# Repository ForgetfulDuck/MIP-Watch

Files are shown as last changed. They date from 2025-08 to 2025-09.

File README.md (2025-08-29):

# STM32 Fitness Tracker with MIP Display
A simple fitness tracker based on the STM32U0 microcontroller that utilizes low-power modes, DMA-based I2C data transfers, and an ultra-low-power MIP display to maximize battery life.
___
### Hardware Components
| Description | Part |
| :--- | ---:|
| Arm Cortex-M0+ MCU  | [STM32U0](/Datasheets/stm32u031f4.pdf) |
| Accelerometer with built-in pedometer  | [LSM6DSR](/Datasheets/LSM6DSR.pdf) |
| RTC  | [MAX31331](/Datasheets/MAX31331.pdf) |
| MIP display  | [TN0104ANVAANN](/Datasheets/TN0104ANVAANN-GN00_Spec.pdf) |
| Coin Cell  (4.2-3.6V, 120mAh )  | LIR2450 |

### Software + Tools
- PCB Design: KiCAD (Schematic and 4-layer board design)
- Firmware Development: STM32CubeIDE with HAL drivers
- Programming: ST-Link V2 debugger/programmer
- Version Control: Git with structured project management
___
### PCB Design
**4-Layer Stackup: Signal - GND - Power - Signal**:
|  | Image | Contents |
| :---:  | :---: | :---: |
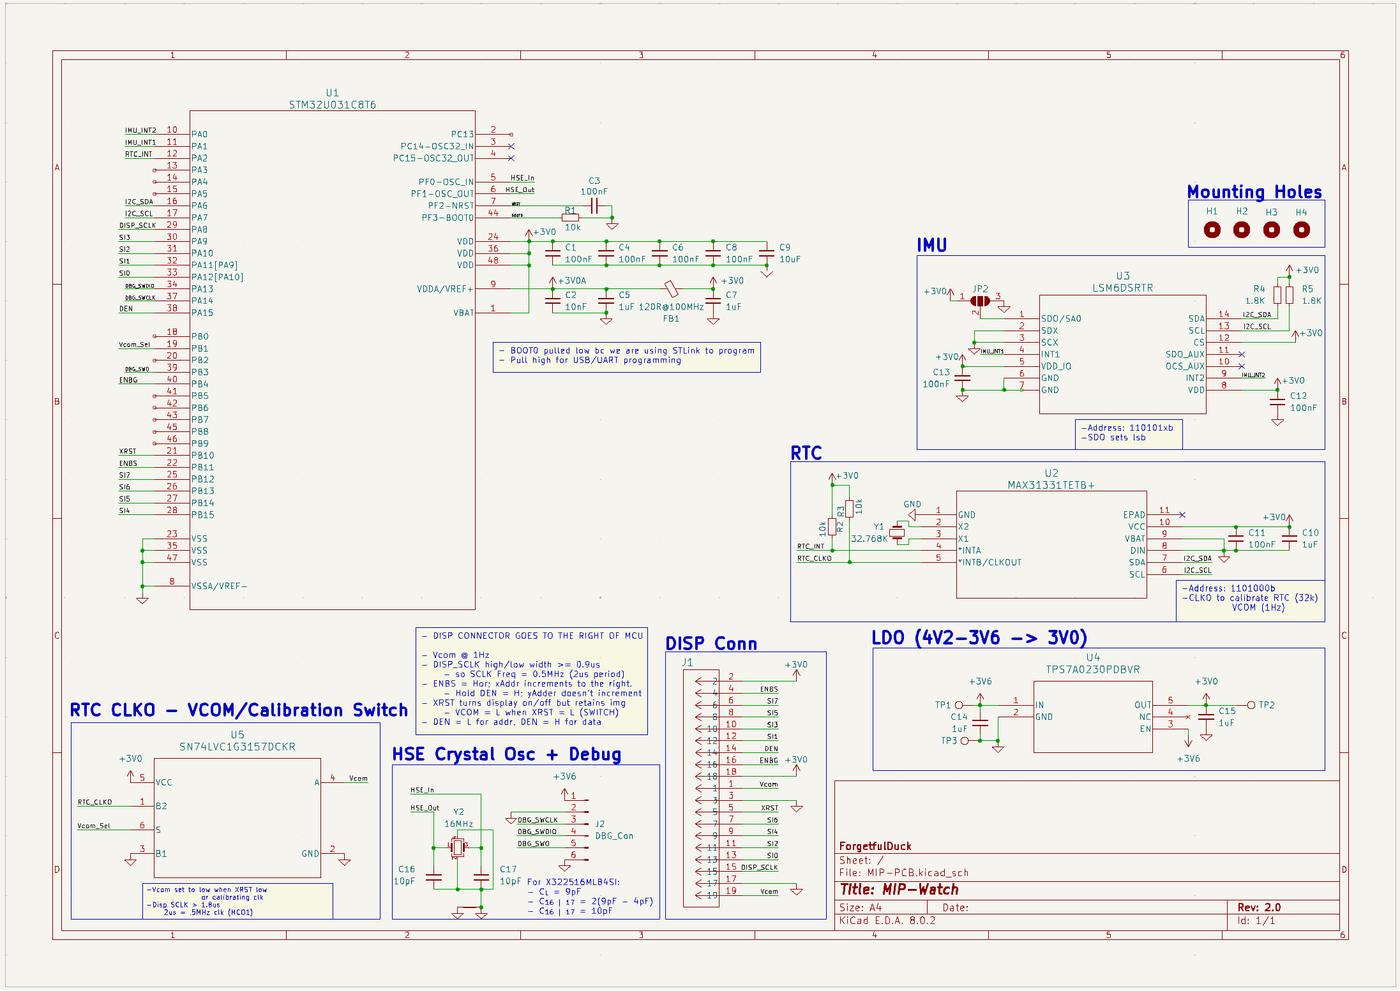
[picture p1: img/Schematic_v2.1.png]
Schematic
|Schematic| |  |
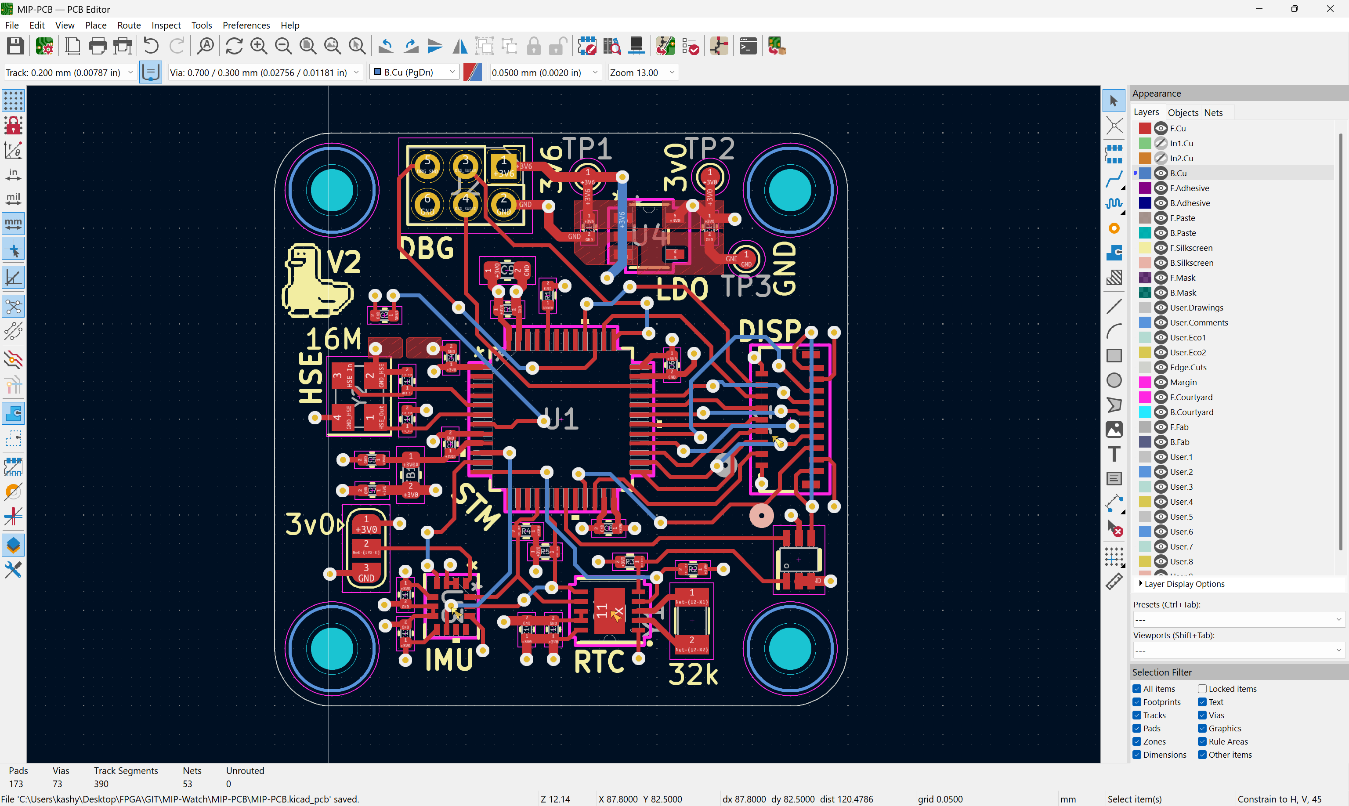
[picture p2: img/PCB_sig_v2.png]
|Signal| | Short traces, Decoupling caps, Copper pours, Test pads |
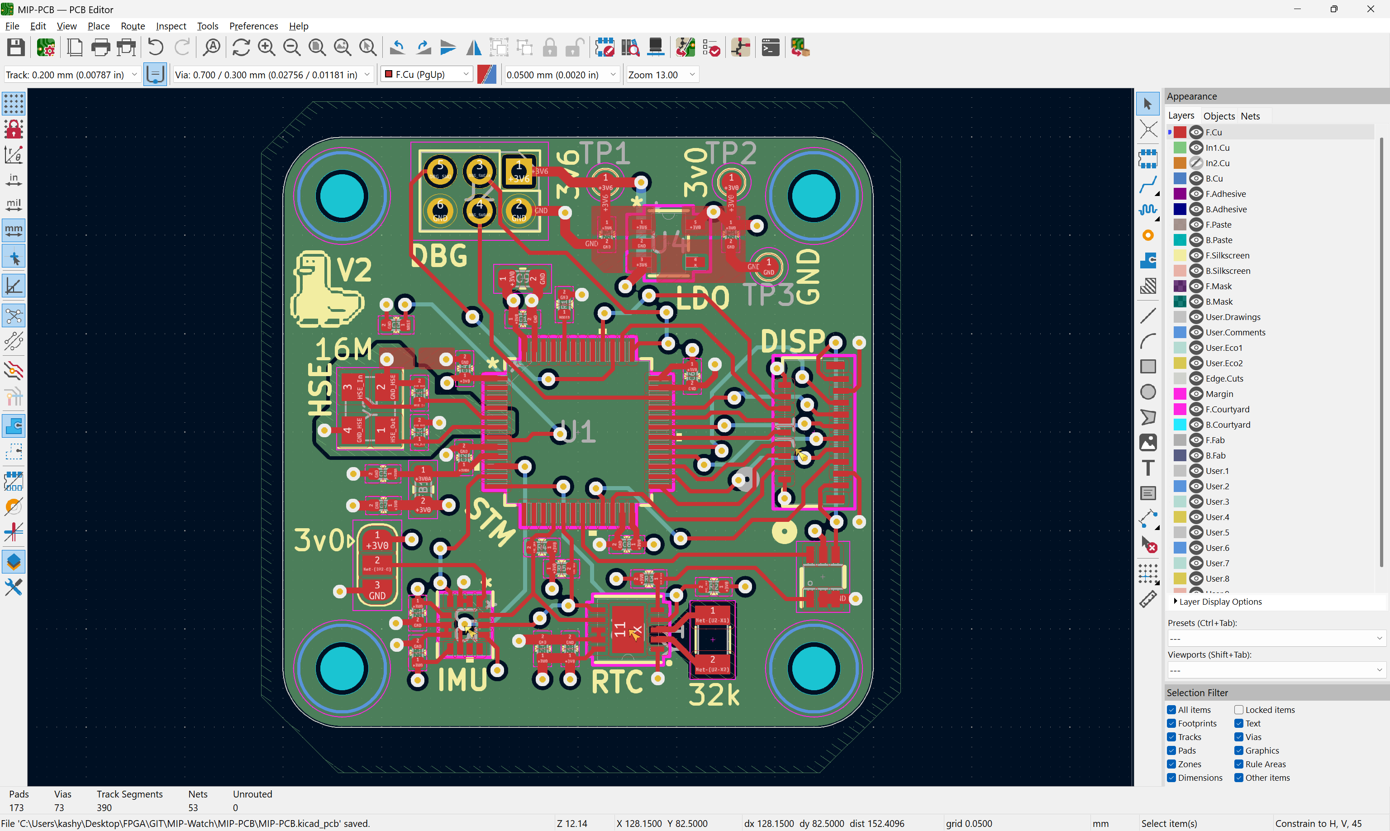
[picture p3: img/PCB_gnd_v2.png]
|GND| | A continuous ground plane to maximize signal integrity and minimize EMI |
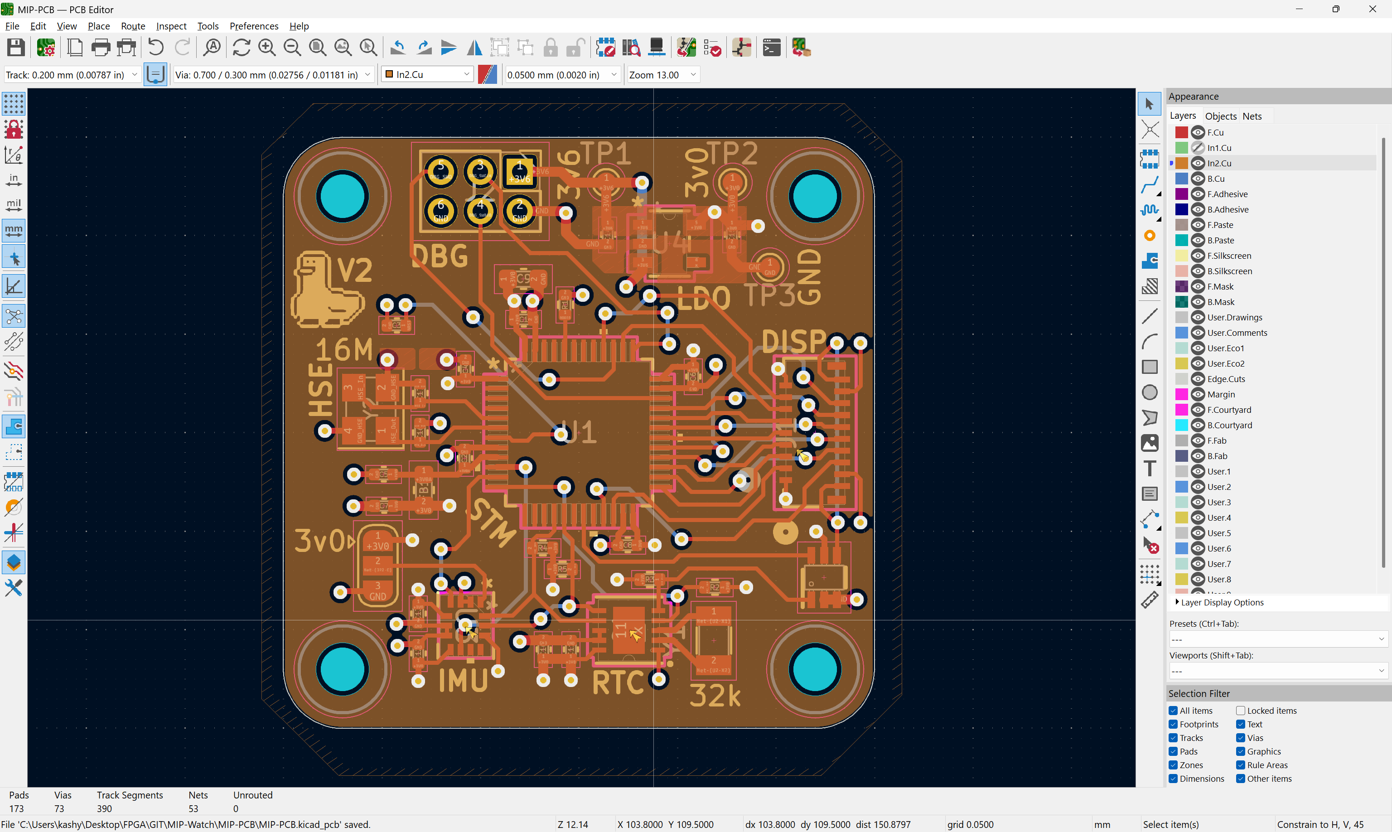
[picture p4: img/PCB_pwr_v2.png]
|Power| |  A clean power plane for efficient power distribution with minimal voltage drop |
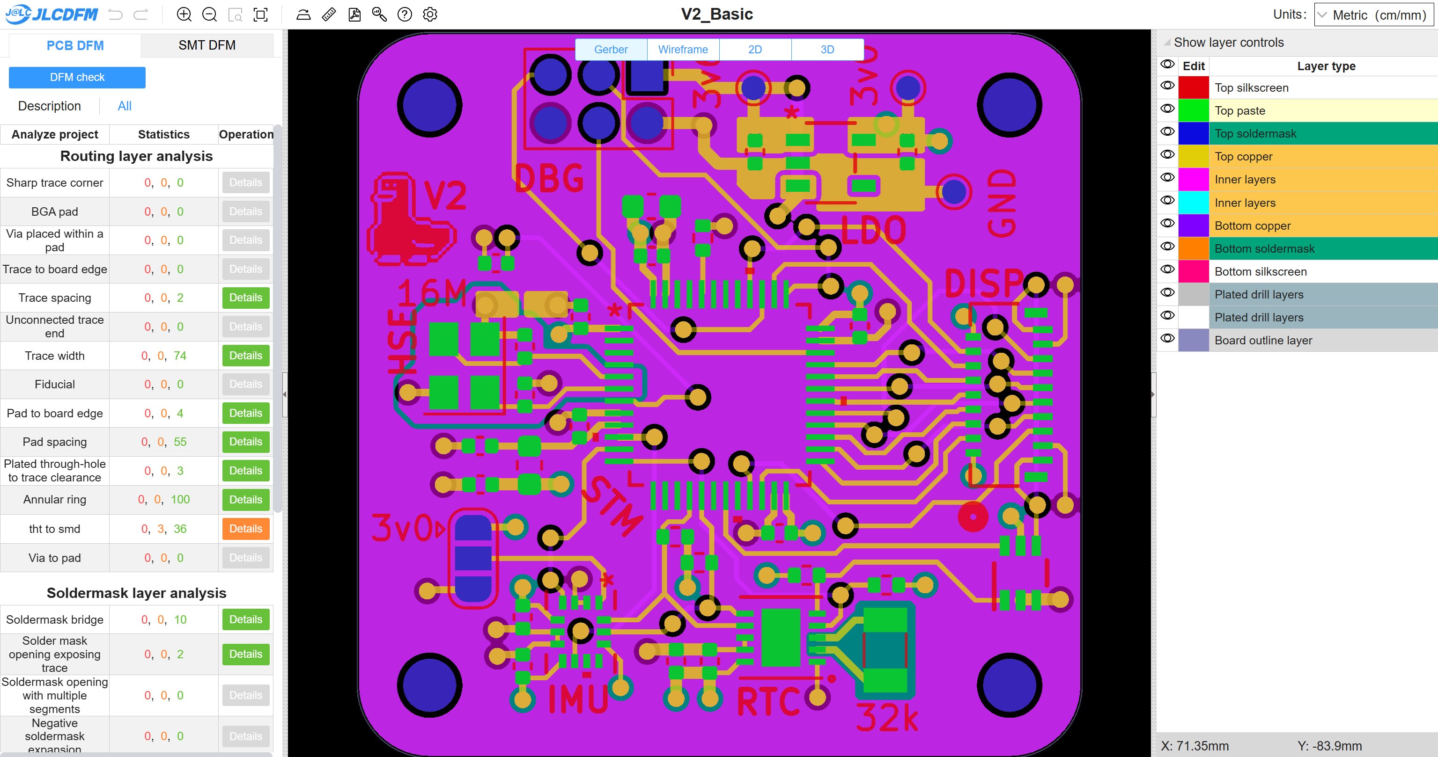
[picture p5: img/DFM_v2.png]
DFM
|DFM | | Designed around JLCPCB's design constraints, with design-for-testability (DFT) considerations, including test points and adequate component spacing. |
___

### System Architecture

```mermaid
---
config:
  theme: base
  themeVariables:
    primaryColor: "#2b3137"
    primaryTextColor: "#fafbfc"
    primaryBorderColor: "#fafbfc"
    lineColor: "#fafbfc"
    secondaryColor: "#24292e"
    tertiaryColor: "#0D1117"
    fontSize: "16px"
    fontFamily: "Segoe UI, Helvetica, Arial, sans-serif"
  nodeSpacing: 30
  rankSpacing: 30
---
flowchart TD
   subgraph SystemArchitecture [ ]
      A[Power On Reset] --> B[MCU Core Initialization<br>HAL, Clock, I2C Bus Clear]
      B --> C[Peripheral Setup<br>GPIO, DMA, I2C,<br>RTC, IMU, Interrupts]
      
      C --> D[Main Control Loop]
      
      D --> E{Job in Queue?}
      E --> F[No] --> G[Enter STOP Mode]
      G --> H[Wait for Sensor Interrupt]
      
      E --> I[Yes] --> J{DMA Available?}
      J --> K[No] --> L[Enter SLEEP Mode]
      L --> M[Wait for DMA Line]
      
      J --> N[Yes] --> O[Start DMA Transfer] --> L
      
      subgraph InterruptSources [Interrupt Handler]
      style InterruptSources fill:#2dba4e,stroke:#ffffff,stroke-width:2px,color:#ffffff
         P[IMU INT1: Step Detection] --> Q[Enqueue Step<br>Job]
         R[IMU INT2: Tap Detection] --> S[Enqueue Tap<br>Job]
         T[RTC INT: Timer Tick] --> U[Enqueue Time<br>Job]
         V[DMA Complete] --> W[Process Sensor Data<br>&<br>Free DMA Resources]
      end
      
      Q --> D
      S --> D
      U --> D
      W --> D
   end
```
___
### Key Features
- **Interrupt-driven firmware:** Interrupts from sensors queue jobs, preventing the need to continuously poll for updated data.
   - The IMU handles step/tap detection and only wakes the MCU when a new event occurs.
   - The RTC generates periodic interrupts for timekeeping and display refreshes.
- **Custom RTC Driver:** Wrote a platform-independent driver for the MAX31331 that provides:
   - Time/date get + set functions
   - Timer configuration + clock calibration
   - Interrupt setup
- **Direct Memory Access (DMA):** I²C data from the sensors is transferred in the background, while the CPU is in SLEEP mode.
- **Dynamic Power Management:** The firmware enters STOP mode when idle and SLEEP mode during DMA operations, waking only to process data from the sensors.
- **Memory-in-Pixel (MIP) display:** The display only consumes energy when the content is updated.

### Build & Flash
- Open project in STM32CubeIDE.
- Build firmware (`Project → Build Project`).
- Connect ST-Link V2 over SWD
   - SWDIO → SWDIO
   - SWCLK → SWCLK
   - VCC   → 3.6-5V
   - GND   → GND
- Flash firmware (`Run -> Run/Debug`)

### Debugging
   - Arm Cortex-M0+ MCUs do not support SWV, so SWO debug output is unavailable.
   - Use CubeIDE debugger with:
      - Breakpoints for interrupt handling.
      - Live Expressions to monitor variables (e.g., step counts, clock).
___
### Roadmap
- **User Input:** Add tactile buttons for UI interaction.
- **Power System:** Integrate a coin-cell holder with a BMS for charging support.
- **Peripheral Control:** Dedicate pins on the MCU to enable/disable sensors for proper power sequencing.
- **UART:** Add UART RX/TX headers for logging & debug.
- **Future Plans:** BLE, heart-rate sensor.

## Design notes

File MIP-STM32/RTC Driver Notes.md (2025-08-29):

RTC initialization:

 	Reset RTC

 		(Register 0x2) = 1 // Resets

 	Release Reset (release built into reset function)

 		(Register 0x2) = 0 // Normal

 	========================================================

 	Set Seconds

 		(Register 0x8) = BCD(seconds)
 	Set Minutes

 		(Register 0x9) = BCD(minutes)

 	Set Hours (plus format)

 		(Register 0xA) = if (format == HOUR24) {

 				 	regs->hours\_reg.bcd\_24hr.value = BIN2BCD(time->tm\_hour);

        				regs->hours\_reg.bits\_24hr.f\_24\_12 = HOUR24;

 				 } else if (format == HOUR12) {

        				uint8\_t hr\_12, pm;

        				to\_12hr(time->tm\_hour, \&hr\_12, \&pm);

        				regs->hours\_reg.bcd\_12hr.value = BIN2BCD(hr\_12);

        				regs->hours\_reg.bits\_12hr.f\_24\_12 = HOUR12;

        				regs->hours\_reg.bits\_12hr.am\_pm = pm;

    				} else {

      					pr\_err("Invalid Hour Format!");

        				return MAX3133X\_INVALID\_TIME\_ERR;

    				}

 	Set Days...Year

 		(Register 0xB-E) = BCD(...)

 	!!! Calculate 7 bytes (seconds to year) in one go and transfer data once

 	========================================================

 	Read Same registers to verify RTC Works as expected

 	!!! Read back 7 bytes (seconds to year) in one read command

 	========================================================

RTC Calibration:

 	Enable uncalibrated CLKO at 32kHz:

 		(Register 0x4) = 0b111 (uncorrected 32kHz on INTB)

 	========================================================

 	Measure freq using logic analyzer or oscilloscope

 	========================================================

 	Apply offset:
ACCuracy = ((Meas - 32,768) \* 10^6 ) / 32,768

 		Offset  = int{ACC/0.477}

 		Offset (Regs 0x1D,1E) = offset{15:8}, offset{7:0}

 	========================================================

Enable Interrupts:

 	Enable CLKO on INTB (timer and all alarms move to INTA)

 		(Register 0x4) = 0b100 (Corrected 1Hz on INTB)

 	========================================================

 	Configure Timer

 		(Register 0x6) = 1010 (64Hz timer that loops back to initial value once it reaches zero)

 		(Register 0x19) = 1 (timer is has initial value of 1)

 		(Register 0x1) = 0b100 (enables timer interrupt)

 			(Read 0x0) should be 0b100 for timer

 			This clears interrupt status after each interrupt

 	========================================================

Update time:

 	Every interrupt, read status bit

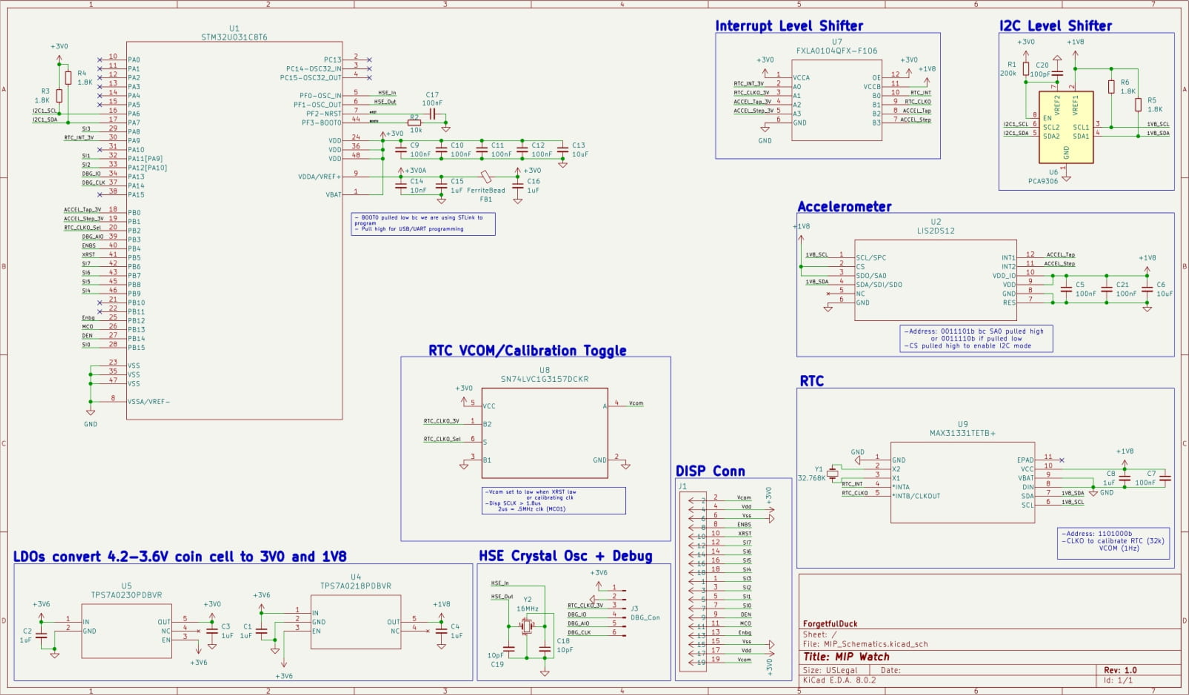
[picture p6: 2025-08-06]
img/Schematic.png

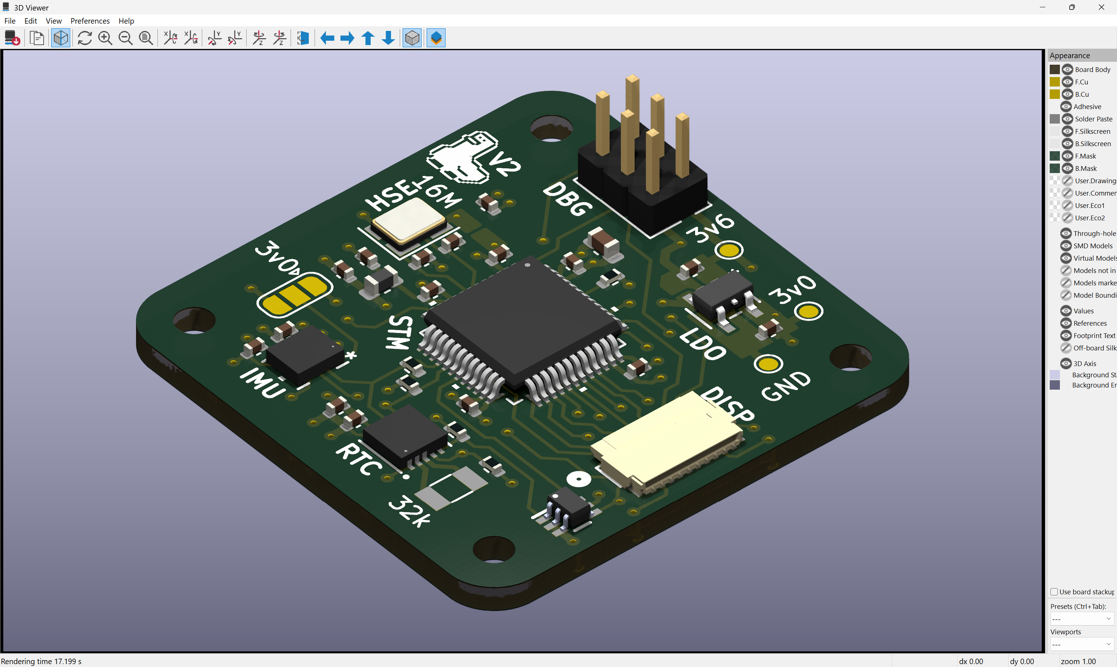
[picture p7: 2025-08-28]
img/PCB_Render_v2.png

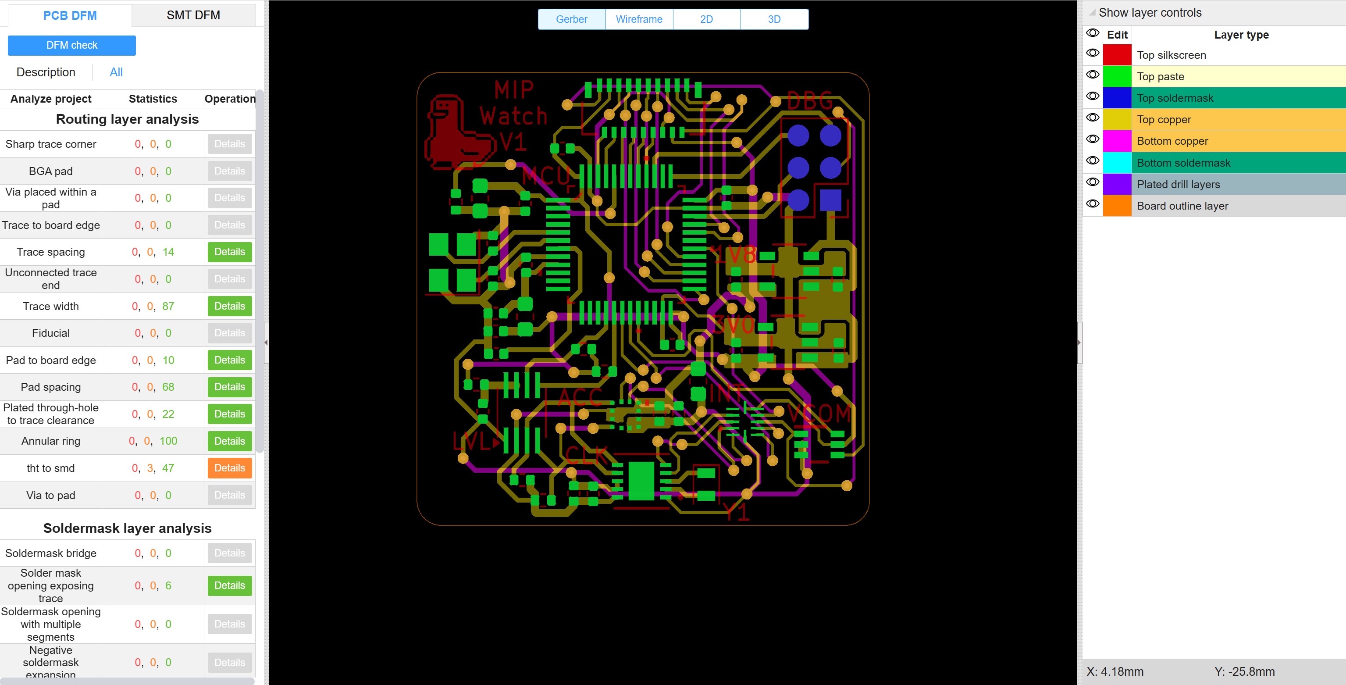
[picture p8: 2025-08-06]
img/DFM.png

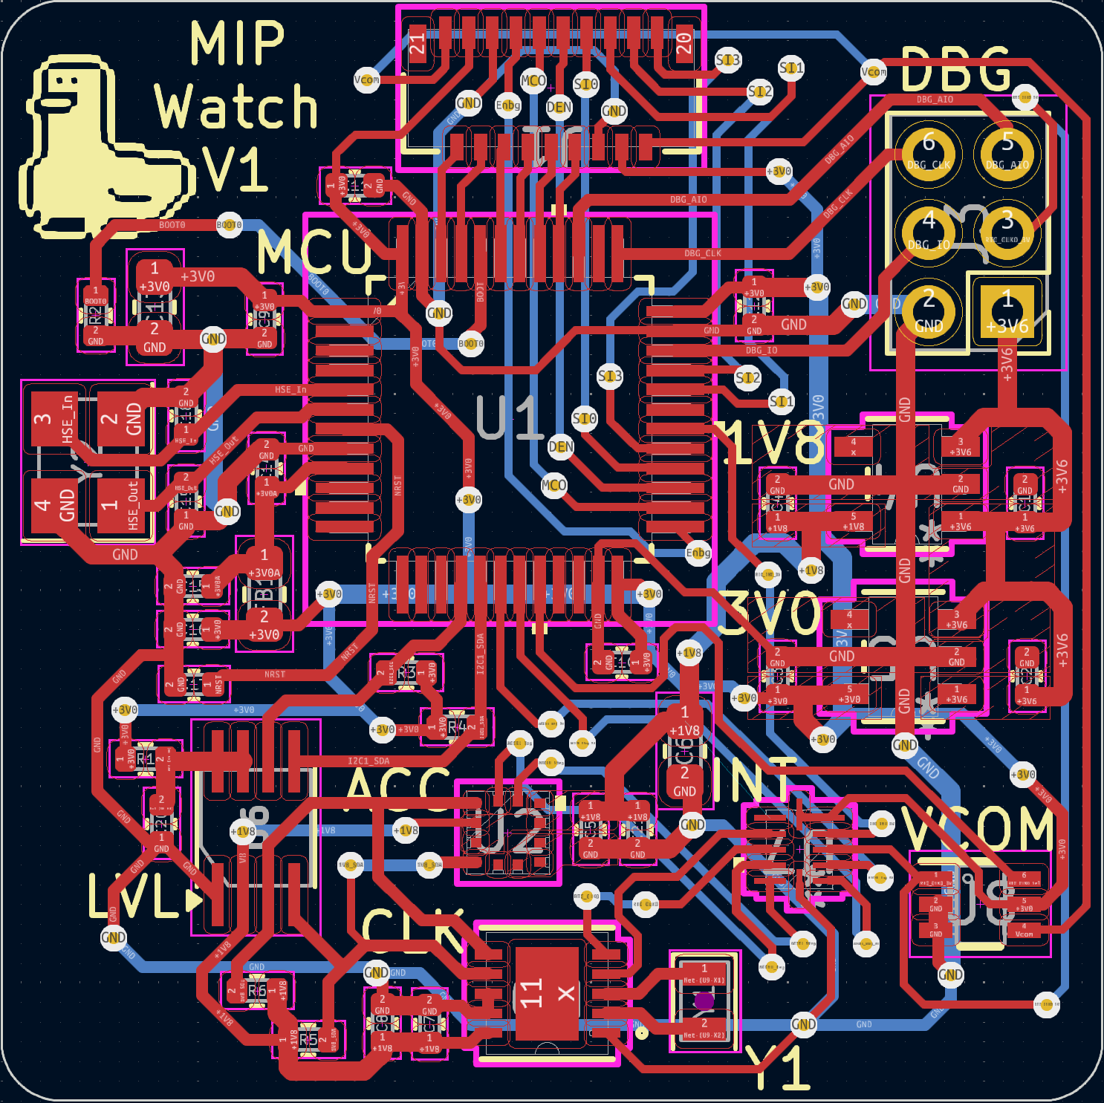
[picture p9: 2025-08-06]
img/PCB.png

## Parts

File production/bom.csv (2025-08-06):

Designator | Footprint | Quantity | Value | LCSC Part #
C1, C15, C16, C2, C3, C4, C8 | 0402 | 7 | 1uF
C10, C11, C12, C17, C21, C5, C7, C9 | 0402 | 8 | 100nF
C13, C6 | 0603 | 2 | 10uF
C14 | 0402 | 1 | 10nF
C18, C19 | 0402 | 2 | 10pF
C20 | 0402 | 1 | 100pF
FB1 | 0603 | 1 | FerriteBead
J1 | CONN19_FH35C-19S-0.3SHW99_HIR | 1 | FH35C-19S-0.3SHW99
J3 | PinHeader_2x03_P2.00mm_Vertical | 1 | DBG_Con
R1 | 0402 | 1 | 200k
R2 | 0402 | 1 | 10k
R3, R4, R5, R6 | 0402 | 4 | 1.8K
U1 | LQFP48_STM | 1 | STM32U031C8T6
U2 | LGA-12_2X2X0P86_STM | 1 | LIS2DS12
U4 | SOT_233DBVR_TEX | 1 | TPS7A0218PDBVR
U5 | SOT23_DBV_TEX | 1 | TPS7A0230PDBVR
U6 | SSOP-8_2.95x2.8mm_P0.65mm | 1 | PCA9306
U7 | UMLP12_1P7X2_ONS | 1 | FXLA0104QFX-F106
U8 | DCK0006A_N | 1 | SN74LVC1G3157DCKR
U9 | 21-0137_T1033-1C_MXM | 1 | MAX31331TETB+
Y1 | Crystal_SMD_2012-2Pin_2.0x1.2mm | 1 | 128k
Y2 | Crystal_SMD_3225-4Pin_3.2x2.5mm | 1 | 16MHz

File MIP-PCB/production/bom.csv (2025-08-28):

Designator | Footprint | Quantity | Value | LCSC Part #
C1, C11, C12, C13, C3, C4, C6, C8 | 0402 | 8 | 100nF
C10, C14, C15, C5, C7 | 0402 | 5 | 1uF
C16, C17 | 0402 | 2 | 10pF
C2 | 0402 | 1 | 10nF
C9 | 0603 | 1 | 10uF
FB1 | 0603 | 1 | 120R@100MHz
J1 | CONN19_FH35C-19S-0.3SHW99_HIR | 1 | FH35C-19S-0.3SHW99
J2 | PinHeader_2x03_P2.00mm_Vertical | 1 | DBG_Con
R1, R2, R3 | 0402 | 3 | 10k
R4, R5 | 0402 | 2 | 1.8K
TP1, TP2, TP3 | TestPoint_Pad_D1.0mm | 3 | TestPoint
U1 | LQFP48_STM-L | 1 | STM32U031C8T6
U2 | 21-0137_T1033-1C_MXM | 1 | MAX31331TETB+
U3 | LGA-14L_2P5X3X0P83_STM-L | 1 | LSM6DSRTR
U4 | SOT23_DBV_TEX | 1 | TPS7A0230PDBVR
U5 | DCK0006A_N | 1 | SN74LVC1G3157DCKR
Y1 | Crystal_SMD_3215-2Pin_3.2x1.5mm | 1 | 32.768K
Y2 | Crystal_SMD_3225-4Pin_3.2x2.5mm | 1 | 16MHz

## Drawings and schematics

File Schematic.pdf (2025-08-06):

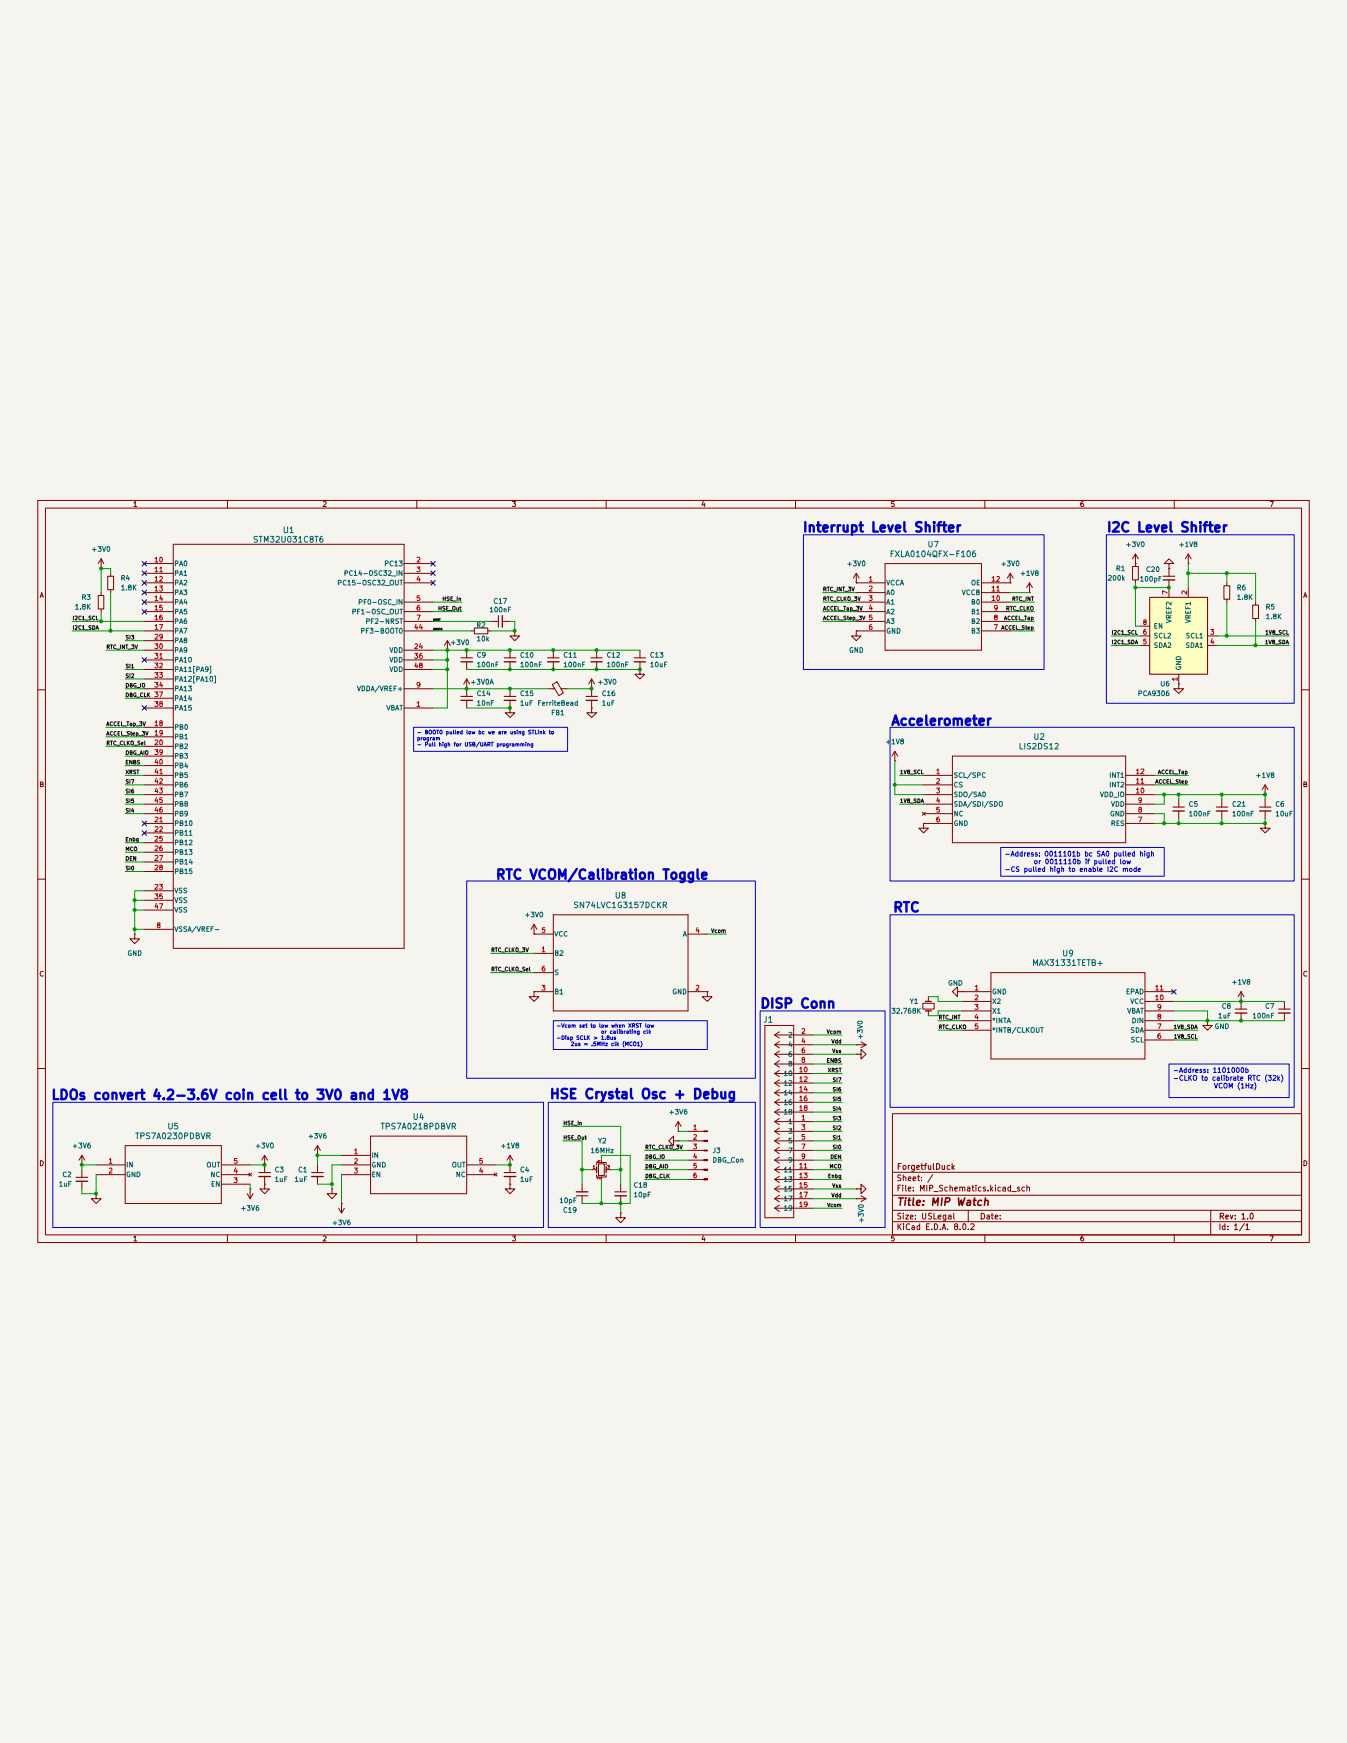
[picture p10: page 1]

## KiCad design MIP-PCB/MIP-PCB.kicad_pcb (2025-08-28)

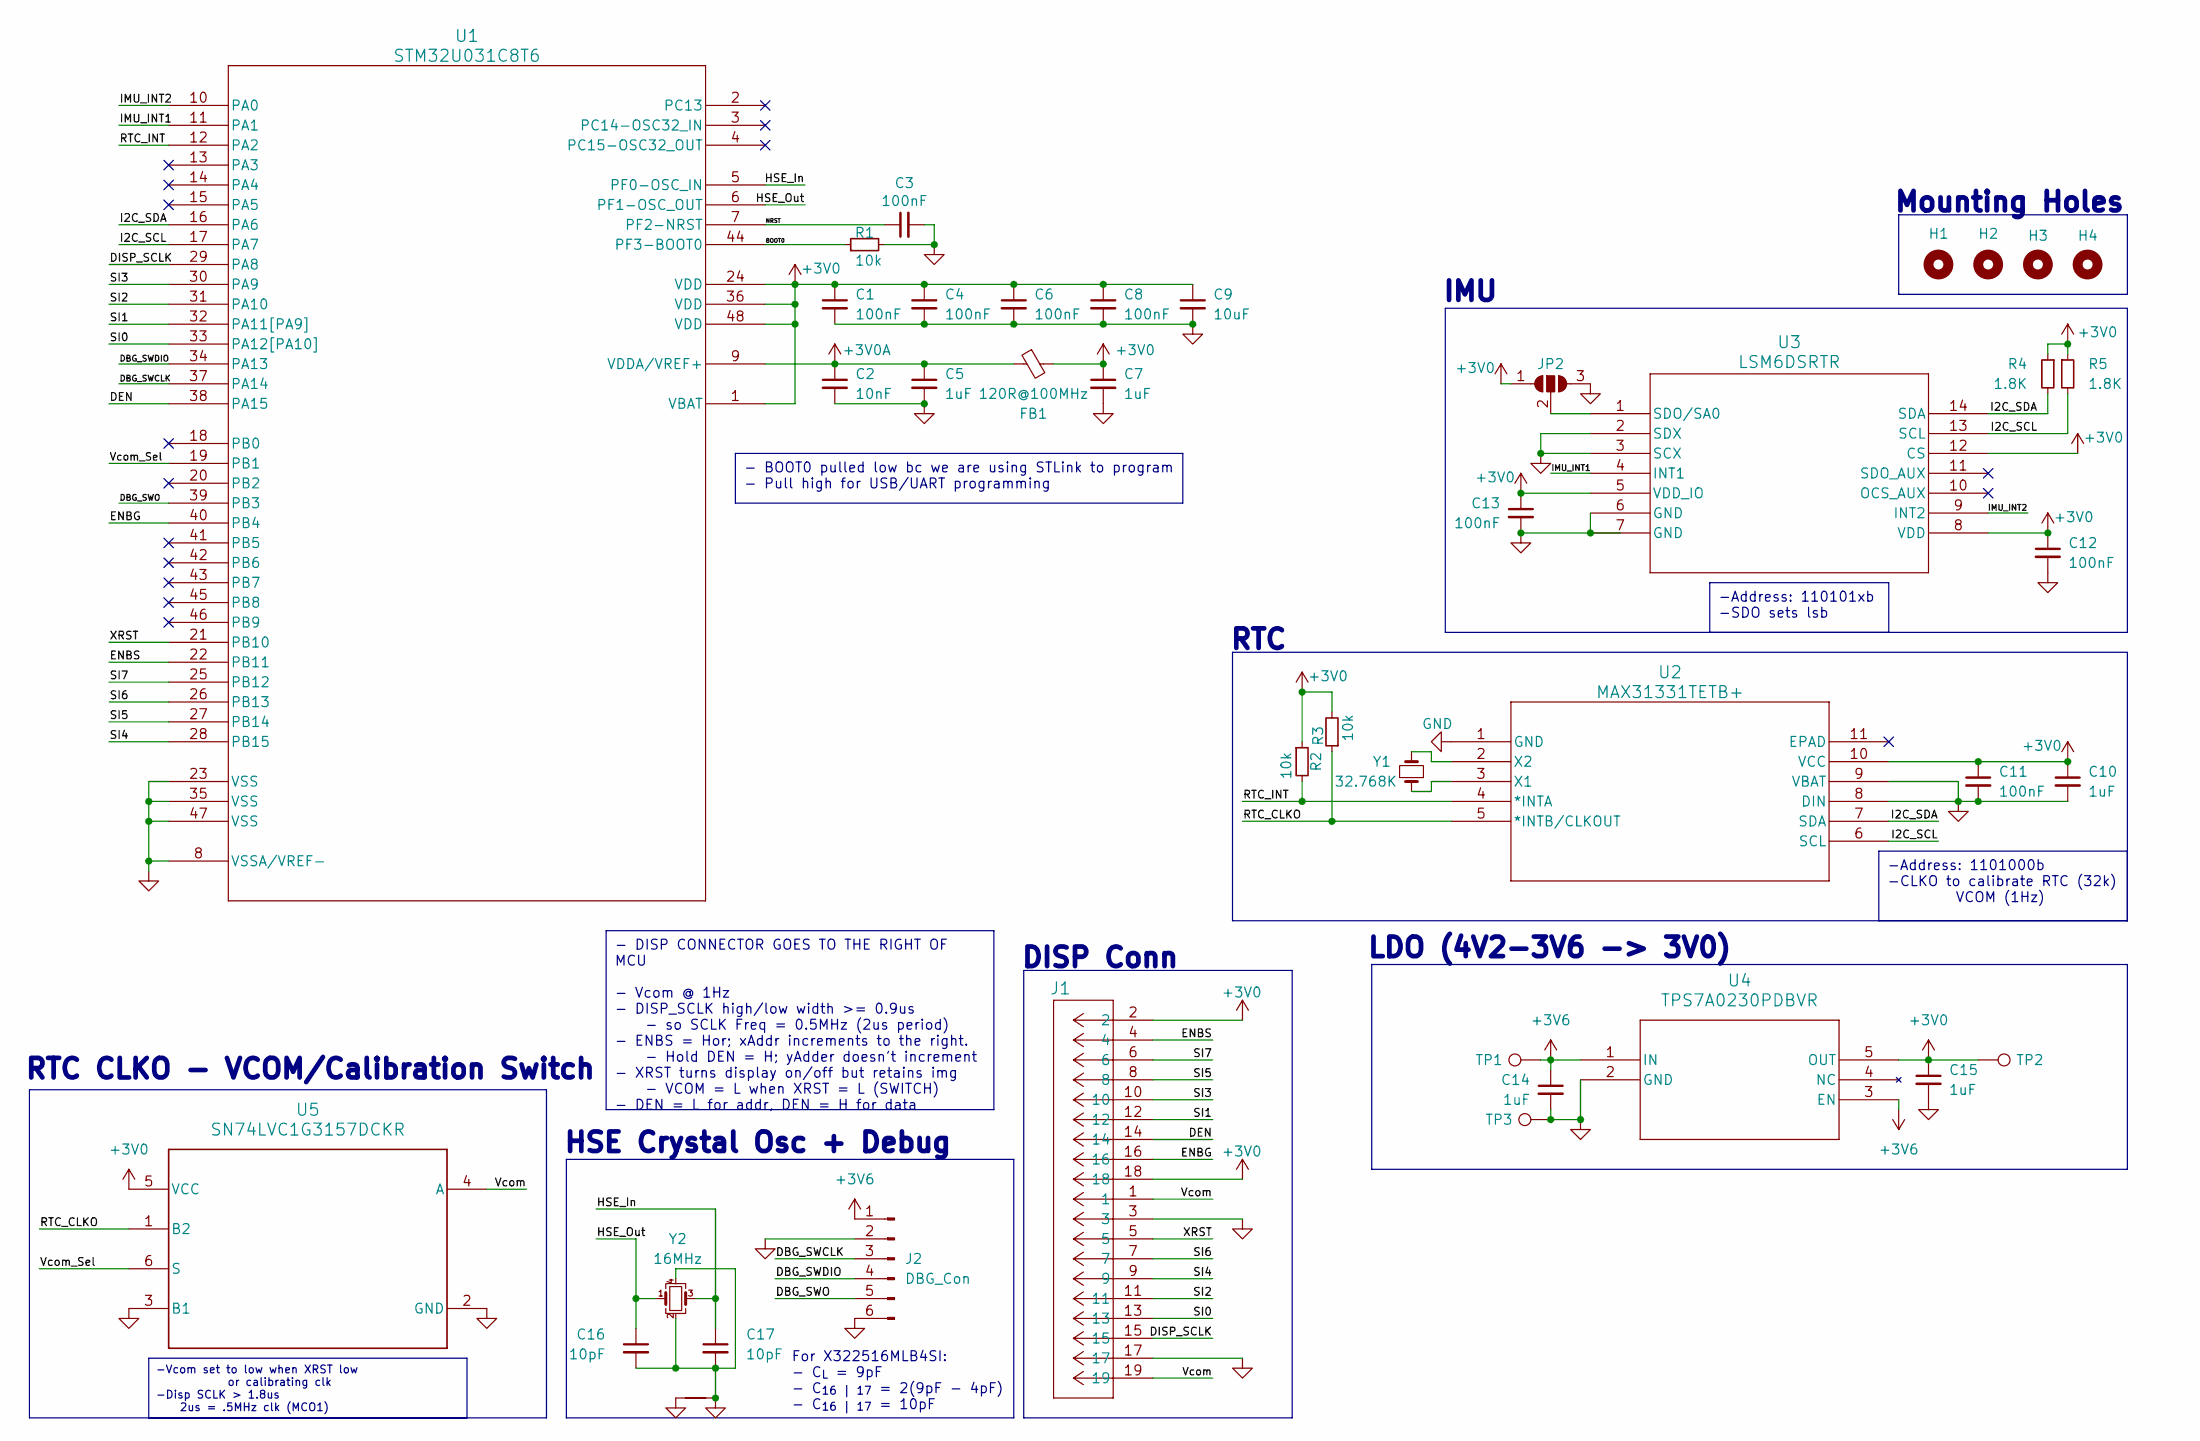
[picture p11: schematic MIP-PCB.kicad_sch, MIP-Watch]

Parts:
C1, C3, C4, C6, C8, C11, C12, C13: 100nF; C_0402_1005Metric
C2: 10nF; C_0402_1005Metric
C5, C7, C10, C14, C15: 1uF; C_0402_1005Metric
C9: 10uF; C_0603_1608Metric
C16, C17: 10pF; C_0402_1005Metric
FB1: 120R@100MHz; L_0603_1608Metric
H1, H2, H3, H4: MountingHole; MountingHole_2.2mm_M2
J1: FH35C-19S-0.3SHW99; CONN19_FH35C-19S-0.3SHW99_HIR
J2: DBG_Con; PinHeader_2x03_P2.00mm_Vertical
JP2: SolderJumper_3_Open; SolderJumper-3_P1.3mm_Open_RoundedPad1.0x1.5mm
NT1: NetTie_2
R1, R2, R3: 10k; R_0402_1005Metric
R4, R5: 1.8K; R_0402_1005Metric
TP1, TP2, TP3: TestPoint; TestPoint_Pad_D1.0mm
U1: STM32U031C8T6; LQFP48_STM-L
U2: MAX31331TETB+; 21-0137_T1033-1C_MXM
U3: LSM6DSRTR; LGA-14L_2P5X3X0P83_STM-L
U4: TPS7A0230PDBVR; SOT23_DBV_TEX
U5: SN74LVC1G3157DCKR; DCK0006A_N
Y1: 32.768K; Crystal_SMD_3215-2Pin_3.2x1.5mm
Y2: 16MHz; Crystal_SMD_3225-4Pin_3.2x2.5mm

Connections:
+3V0: C1.1, C4.1, C6.1, C7.1, C8.1, C9.1, C10.1, C11.1, C12.1, C13.1, C15.1, FB1.2, J1.2, J1.18, JP2.1 (A), R2.1, R3.2, R4.1, R5.1, TP2.1, U1.1 (VBAT), U1.24 (VDD), U1.36 (VDD), U1.48 (VDD), U2.10 (VCC), U3.5 (VDD_IO), U3.8 (VDD), U3.12 (CS), U4.5 (OUT), U5.5 (VCC)
+3V0A: C2.1, C5.1, FB1.1, U1.9 (VDDA/VREF+)
+3V6: C14.1, J2.1, TP1.1, U4.1 (IN), U4.3 (EN)
/BOOT0: R1.1, U1.44 (PF3-BOOT0)
/DBG_SWCLK: J2.3, U1.37 (PA14)
/DBG_SWDIO: J2.4, U1.34 (PA13)
/DBG_SWO: J2.5, U1.39 (PB3)
/DEN: J1.14, U1.38 (PA15)
/DISP_SCLK: J1.15, U1.29 (PA8)
/ENBG: J1.16, U1.40 (PB4)
/ENBS: J1.4, U1.22 (PB11)
/HSE_In: C17.1, U1.5 (PF0-OSC_IN), Y2.3
/HSE_Out: C16.1, U1.6 (PF1-OSC_OUT), Y2.1
/I2C_SCL: R5.2, U1.17 (PA7), U2.6 (SCL), U3.13 (SCL)
/I2C_SDA: R4.2, U1.16 (PA6), U2.7 (SDA), U3.14 (SDA)
/IMU_INT1: U1.11 (PA1), U3.4 (INT1)
/IMU_INT2: U1.10 (PA0), U3.9 (INT2)
/NRST: C3.1, U1.7 (PF2-NRST)
/RTC_CLKO: R3.1, U2.5 (*INTB/CLKOUT), U5.1 (B2)
/RTC_INT: R2.2, U1.12 (PA2), U2.4 (*INTA)
/SI0: J1.13, U1.33 (PA12[PA10])
/SI1: J1.12, U1.32 (PA11[PA9])
/SI2: J1.11, U1.31 (PA10)
/SI3: J1.10, U1.30 (PA9)
/SI4: J1.9, U1.28 (PB15)
/SI5: J1.8, U1.27 (PB14)
/SI6: J1.7, U1.26 (PB13)
/SI7: J1.6, U1.25 (PB12)
/Vcom: J1.1, J1.19, U5.4 (A)
/Vcom_Sel: U1.19 (PB1), U5.6 (S)
/XRST: J1.5, U1.21 (PB10)
GND: C1.2, C2.2, C3.2, C4.2, C5.2, C6.2, C7.2, C8.2, C9.2, C10.2, C11.2, C12.2, C13.2, C14.2, C15.2, J1.3, J1.17, J2.2, J2.6, JP2.3 (B), NT1.1, R1.2, TP3.1, U1.8 (VSSA/VREF-), U1.23 (VSS), U1.35 (VSS), U1.47 (VSS), U2.1 (GND), U2.8 (DIN), U2.9 (VBAT), U3.2 (SDX), U3.3 (SCX), U3.6 (GND), U3.7 (GND), U4.2 (GND), U5.2 (GND), U5.3 (B1)
GND_HSE: C16.2, C17.2, NT1.2, Y2.2, Y2.4
unnamed: JP2.2 (C), U3.1 (SDO/SA0)
unnamed: U2.3 (X1), Y1.1
unnamed: U2.2 (X2), Y1.2

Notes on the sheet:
-Address: 1101000b -CLKO to calibrate RTC (32k) VCOM (1Hz)
-Address: 110101xb -SDO sets lsb
- BOOT0 pulled low bc we are using STLink to program - Pull high for USB/UART programming
- DISP CONNECTOR GOES TO THE RIGHT OF MCU - Vcom @ 1Hz - DISP_SCLK high/low width >= 0.9us - so SCLK Freq = 0.5MHz (2us period) - ENBS = Hor; xAddr increments to the right. - Hold DEN = H; yAdder doesn't increment - XRST turns display on/off but retains img - VCOM = L when XRST = L (SWITCH) - DEN =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
-Vcom set to low when XRST low or calibrating clk -Disp SCLK > 1.8us 2us = .5MHz clk (MCO1)
RTC
LDO (4V2-3V6 -> 3V0)
For X322516MLB4SI: - C_{L} = 9pF - C_{16 | 17} = 2(9pF - 4pF) - C_{16 | 17} = 10pF
Mounting Holes
HSE Crystal Osc + Debug
RTC CLKO - VCOM/Calibration Switch
IMU
DISP Conn

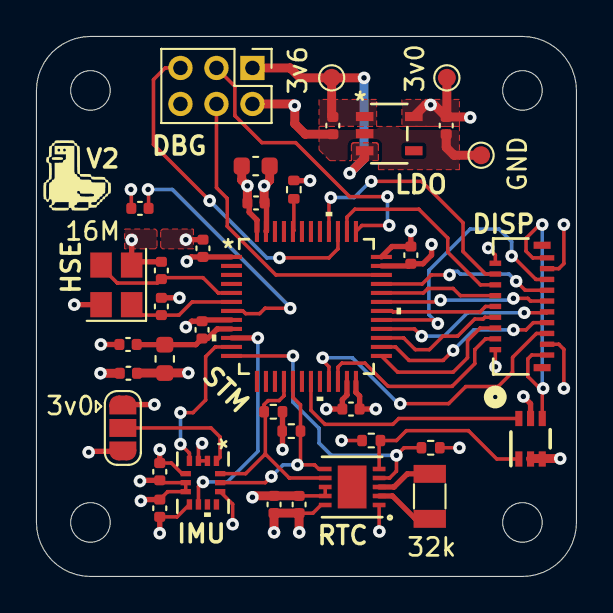
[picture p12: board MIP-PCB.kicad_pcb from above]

Board: 4 copper layers, 30.0 x 30.0 mm, 40 parts (0 on the bottom side), 36 nets.

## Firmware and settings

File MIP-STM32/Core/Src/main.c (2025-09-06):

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
/* Includes ------------------------------------------------------------------*/
#include "main.h"

/* USER CODE BEGIN Includes */
#include "lsm6dsr_reg.h"
#include "max31331_reg.h"

#include <stdio.h>
/* USER CODE END Includes */


I2C_HandleTypeDef hi2c3;
DMA_HandleTypeDef hdma_i2c3_rx;

/* USER CODE BEGIN PV */
/* ============== I2C Variables ============== */
typedef struct {
  I2C_HandleTypeDef *i2c;
  uint16_t addr_8bit;   // 7-bit I2C address (unshifted)
} i2c_dev_t;

static stmdev_ctx_t   s_lsm_ctx;
static max31331_ctx_t s_max_ctx;

static i2c_dev_t g_imu_bus = {
  .i2c = &hi2c3,
  .addr_8bit = (LSM6DSR_I2C_ADD_L)
};

static i2c_dev_t g_rtc_bus = {
  .i2c = &hi2c3,
  .addr_8bit = (MAX31331_I2C_ADD)
};

/* ============== JOB QUEUE VARIABLES ============== */
#define QUEUE_SIZE 16

typedef struct {
    int data[QUEUE_SIZE];
    int front;
    int rear;
    int count;
} JobQueue;

enum JobTypes {
  stepJob = 0,
  tapJob  = 1,
  timeJob = 2
};

volatile JobQueue jobQueue;
volatile uint8_t tapsInQueue = 0;
volatile uint8_t stepsInQueue = 0;
volatile uint8_t timeInQueue = 0;

volatile uint8_t DMArunning = 0;
volatile uint8_t TickDMAflag = 0;
volatile uint8_t TickRXcomp = 0;
volatile uint8_t TapDMAflag = 0;
volatile uint8_t TapRXcomp = 0;
volatile uint8_t StepDMAflag = 0;
volatile uint8_t StepRXcomp = 0;


/* ============== IMU VARIABLES ============== */
// Min # of steps before interrupts
#define STEP_DEBOUNCE_THRESHOLD 8
// DMA RX buffers
uint8_t s_step_rx_buf[2];
uint8_t s_tap_rx_buf[1];
/* Tracked values */
static volatile uint16_t g_step_count = 0;
static volatile uint16_t g_num_taps = 0;

/* ============== RTC VARIABLES ============== */
static uint8_t s_rtc_rx_buf[8];
static uint8_t g_RTC_time[8];

/* ============== Interrupt Setup ============== */
#define IMU_INT1_Pin            GPIO_PIN_1
#define IMU_INT1_GPIO_Port      GPIOA

#define IMU_INT2_Pin 			GPIO_PIN_0
#define IMU_INT2_GPIO_Port 		GPIOA

#define RTC_INT_Pin 			GPIO_PIN_2
#define RTC_INT_GPIO_Port 		GPIOA

#define I2C3_SCL_PIN 			GPIO_PIN_7
#define I2C3_SDA_PIN 			GPIO_PIN_6
#define I2C3_PORT 				GPIOA

static uint8_t inStopMode  = 0;
static uint8_t inSleepMode = 0;
static uint8_t inLPRunMode = 0;
/* USER CODE END PV */

void SystemClock_Config(void);
static void MX_GPIO_Init(void);
static void MX_DMA_Init(void);
static void MX_I2C3_Init(void);
/* USER CODE BEGIN PFP */
/* ============== JOB QUEUE FUNCTIONS ============== */
void initJobQueue(volatile JobQueue *q);
int isJobsEmpty(volatile JobQueue *q);
int isJobsFull(volatile JobQueue *q);
int enqueueJob(volatile JobQueue *q, int value);
int dequeueJob(volatile JobQueue *q, int *value);
static void startJob(int job);
static void processJob(void);
int job = 5;

/* ============== I2C DEVICE FUNCTIONS ============== */
static int32_t platform_write(void *handle, uint8_t reg, const uint8_t *bufp, uint16_t len);
static int32_t platform_read (void *handle, uint8_t reg, uint8_t *bufp, uint16_t len);
static void clear_I2C_bus(void);

/* ============== LP-Run modes ============== */
void Enter_LowPowerRunMode(void);
void Exit_LowPowerRunMode(void);

/* ============== I2C DEVICE INIT FUNCTIONS ============== */
static void LSM6DSR_Init(void);
static void LSM6DSR_Init_Tap_INT2(void);
static void LSM6DSR_Init_Pedo_INT2(void);
static void MAX31331_Init(void);
/* USER CODE END PFP */

/**
  * @brief  The application entry point.
  * @retval int
  */
int main(void)
{

  /* MCU Configuration--------------------------------------------------------*/

  /* Reset of all peripherals, Initializes the Flash interface and the Systick. */
  HAL_Init();

  /* USER CODE BEGIN Init */
//   reconfigure_interupts(0); // Configure IMU interrupt pins as GPIO outputs set to 0
//   __HAL_RCC_GPIOA_CLK_ENABLE();
  clear_I2C_bus();
  /* USER CODE END Init */

  /* Configure the system clock */
  SystemClock_Config();

  /* Initialize all configured peripherals */
  MX_GPIO_Init();
  MX_DMA_Init();
  MX_I2C3_Init();
  /* USER CODE BEGIN 2 */

  tapsInQueue = 0;
  stepsInQueue = 0;
  timeInQueue = 0;
  
  DMArunning 	= 0;
  TickDMAflag 	= 0;
  TickRXcomp 	= 0;

  TapDMAflag 	= 0;
  TapRXcomp 	= 0;
  
  StepDMAflag 	= 0;
  StepRXcomp 	= 0;

  inStopMode  = 0;
  inSleepMode = 0;

  LSM6DSR_Init();
//   reconfigure_interupts(1); // Configure IMU interrupt pins as EXTI
  
  MAX31331_Init();

  initJobQueue(&jobQueue);

  HAL_Delay(1000); // Prevent immediate stop/sleep mode entry
  
  Enter_LowPowerRunMode(); // Sets SysClk Source to MSI @ 1MHz
  /* USER CODE END 2 */

  /* Infinite loop */
  /* USER CODE BEGIN WHILE */
  while (1)
  {
    /* USER CODE END WHILE */

    /* USER CODE BEGIN 3 */

//    HAL_Delay(1);

    // Parse data from complete jobs
    processJob();
    
    // If DMA is free and job queue !empty, start job
    if(!DMArunning) {
    	if (dequeueJob(&jobQueue, &job)) { // If job in queue, start it
    		startJob(job);
    	} else {// else job queue is empty, go back to STOP mode while we wait for next interrupt
    		inStopMode = 1;
    		HAL_SuspendTick();
    		HAL_PWREx_EnterSTOP2Mode(PWR_STOPENTRY_WFI);

    		HAL_ResumeTick();
    		inStopMode = 0;
	   }
    } else {// Waiting for DMA to finish, go back to SLEEP mode while we wait for I2C callback
	 	inSleepMode = 1;
	 	HAL_SuspendTick();
	 	HAL_PWR_EnterSLEEPMode(PWR_MAINREGULATOR_ON,PWR_SLEEPENTRY_WFI);

	 	HAL_ResumeTick();
	 	inSleepMode = 0;
	 }
  }
  /* USER CODE END 3 */
}

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
/* USER CODE BEGIN 4 */
/* ============== JOB QUEUE ============== */
void initJobQueue(volatile JobQueue *q) {
    q->front = 0;
    q->rear = -1;
    q->count = 0;
}

int isJobsEmpty(volatile JobQueue *q) {
    return q->count == 0;
}

int isJobsFull(volatile JobQueue *q) {
    return q->count == QUEUE_SIZE;
}

int enqueueJob(volatile JobQueue *q, int value){
	if (isJobsFull(q)) {
        // printf("Queue is full! Cannot enqueue %d\n", value);
        return 0;
    }
    
    q->rear = (q->rear + 1) % QUEUE_SIZE;
    q->data[q->rear] = value;
    q->count++;
    
    return 1;
}

int dequeueJob(volatile JobQueue *q, int *value){
	if (isJobsEmpty(q)) {
        // printf("Queue is empty! Cannot dequeue\n");
        return 0;
    }
    
    *value = q->data[q->front];
    q->front = (q->front + 1) % QUEUE_SIZE;
    q->count--;
    
    return 1;
}

// Start DMA read
static void startJob(int job)
{
	lsm6dsr_func_cfg_access_t func_cfg_access = {0};
	switch (job) {
		case stepJob:
      __disable_irq();
			if (stepsInQueue) stepsInQueue--;
      __enable_irq();
			func_cfg_access.reg_access = LSM6DSR_EMBEDDED_FUNC_BANK; // Enable standard register bank
			if (!HAL_I2C_Mem_Write(&hi2c3, LSM6DSR_I2C_ADD_L, LSM6DSR_FUNC_CFG_ACCESS, I2C_MEMADD_SIZE_8BIT, (uint8_t *)&func_cfg_access, 1, 5)) {
				DMArunning = 1;
				StepDMAflag = 1;
				HAL_I2C_Mem_Read_DMA(&hi2c3, LSM6DSR_I2C_ADD_L, LSM6DSR_STEP_COUNTER_L, I2C_MEMADD_SIZE_8BIT, s_step_rx_buf, 2);
			}
			break;
		case tapJob:
			__disable_irq();
      if (tapsInQueue) tapsInQueue--;
      __enable_irq();
			func_cfg_access.reg_access = LSM6DSR_USER_BANK; // Enable standard register bank
			if(!HAL_I2C_Mem_Write(&hi2c3, LSM6DSR_I2C_ADD_L, LSM6DSR_FUNC_CFG_ACCESS, I2C_MEMADD_SIZE_8BIT, (uint8_t *)&func_cfg_access, 1, 5)) {
				DMArunning = 1;
				TapDMAflag = 1;
				HAL_I2C_Mem_Read_DMA(&hi2c3, LSM6DSR_I2C_ADD_L, LSM6DSR_TAP_SRC, I2C_MEMADD_SIZE_8BIT, s_tap_rx_buf, 1);
			}
			break;
		case timeJob:
			__disable_irq();
			if (timeInQueue) timeInQueue--;
      __enable_irq();
			uint8_t status;
			max31331_get_status(&s_max_ctx, &status); // Clears interrupt
			DMArunning = 1;
			TickDMAflag = 1;
			HAL_I2C_Mem_Read_DMA(&hi2c3, MAX31331_I2C_ADD, MAX31331_SECONDS_1_128, I2C_MEMADD_SIZE_8BIT, s_rtc_rx_buf, 8); // Read sec_128 to year in one go
			break;
		default:
			break;		
		// DMA started, we can go to sleep while we wait for I2C callback
	}
}

// Process DMA data
static void processJob(void) {
	if (TickRXcomp) { // Update Time
		uint8_t s128 = s_rtc_rx_buf[0]; // Unused for now
		uint8_t s  	 = bin2dec_bcd(s_rtc_rx_buf[1] & MAX31331_SECONDS_MSK);
		uint8_t m  	 = bin2dec_bcd(s_rtc_rx_buf[2] & MAX31331_MINUTES_MSK);
		uint8_t h  	 = s_rtc_rx_buf[3];

		uint8_t format  = (h & MAX31331_TS_F24_12_MSK) >> MAX31331_TS_F24_12_POS;
		
		int hour;

		if (format == HOUR24) {
			hour = ((h & MAX31331_HOURS_HOUR_MSK) 		>> MAX31331_HOURS_HOUR_POS) + 
				   (((h & MAX31331_HOURS_HR10_MSK) 		>> MAX31331_HOURS_HR10_POS) * 10) +
				   (((h & MAX31331_HOURS_HR20_AMPM_MSK) >> MAX31331_HOURS_HR20_AMPM_POS) * 20);
		} else {
			uint8_t h12 = ((h & MAX31331_HOURS_HR10_MSK) >> MAX31331_HOURS_HR10_POS) * 10
						+ ((h & MAX31331_HOURS_HOUR_MSK) >> MAX31331_HOURS_HOUR_POS);
			uint8_t am_pm = (h & MAX31331_HOURS_HR20_AMPM_MSK) >> MAX31331_HOURS_HR20_AMPM_POS;
			if (am_pm == AM) {          // AM
				hour = (h12 == 12) ? 0 : h12;
			} else {                    // PM
				hour = (h12 == 12) ? 12 : h12 + 12;
			}
		}

		uint8_t dy 	 = s_rtc_rx_buf[4] & MAX31331_DAY_MSK;
		uint8_t dt 	 = bin2dec_bcd(s_rtc_rx_buf[5] & MAX31331_DATE_MSK);
		uint8_t mn 	 = bin2dec_bcd(s_rtc_rx_buf[6] & MAX31331_MONTH_MSK);
		uint8_t yr 	 = bin2dec_bcd(s_rtc_rx_buf[7] & MAX31331_YEAR_MSK);

		g_RTC_time[0] = s128;
		g_RTC_time[1] = s;
		g_RTC_time[2] = m;
		g_RTC_time[3] = hour;
		g_RTC_time[4] = dy;
		g_RTC_time[5] = dt;
		g_RTC_time[6] = mn;
		g_RTC_time[7] = yr;
		uint8_t status;
		max31331_get_status(&s_max_ctx, &status); // Clears interrupt

		TickRXcomp = 0;
	} else if (TapRXcomp) { // Handle Tap/DoubleTap
		lsm6dsr_tap_src_t *tap_data = (lsm6dsr_tap_src_t *)s_tap_rx_buf;
		if (tap_data->double_tap) {
			g_num_taps = 2;
		} else if (tap_data->single_tap) {
			g_num_taps = 1;
		} else {
			g_num_taps = 0;
		}

		TapRXcomp = 0;
	} else if (StepRXcomp) { // Update Step Count
		g_step_count = (uint16_t)s_step_rx_buf[1] << 8 | (uint16_t)s_step_rx_buf[0];
		StepRXcomp = 0;
		
	}
}

/* ============== I2C Device Initialization ============== */
static void clear_I2C_bus(void) {
	GPIO_InitTypeDef GPIO_InitStruct = {0};

    // Configure SCL/SDA as open-drain outputs
    GPIO_InitStruct.Pin = I2C3_SCL_PIN | I2C3_SDA_PIN;
    GPIO_InitStruct.Mode = GPIO_MODE_OUTPUT_OD;
    GPIO_InitStruct.Pull = GPIO_NOPULL;
    GPIO_InitStruct.Speed = GPIO_SPEED_FREQ_HIGH;
    HAL_GPIO_Init(I2C3_PORT, &GPIO_InitStruct);

    // Release both lines
    HAL_GPIO_WritePin(I2C3_PORT, I2C3_SDA_PIN | I2C3_SCL_PIN, GPIO_PIN_SET);
    HAL_Delay(1);

    // Toggle SCL while SDA is low
    for (int i = 0; i < 9 && HAL_GPIO_ReadPin(I2C3_PORT, I2C3_SDA_PIN) == GPIO_PIN_RESET; i++) {
        HAL_GPIO_WritePin(I2C3_PORT, I2C3_SCL_PIN, GPIO_PIN_SET);
        HAL_Delay(1); // 1 ms, can reduce to 5-10 us
        HAL_GPIO_WritePin(I2C3_PORT, I2C3_SCL_PIN, GPIO_PIN_RESET);
        HAL_Delay(1);
    }

    // Generate STOP condition
    HAL_GPIO_WritePin(I2C3_PORT, I2C3_SDA_PIN, GPIO_PIN_RESET);
    HAL_GPIO_WritePin(I2C3_PORT, I2C3_SCL_PIN, GPIO_PIN_SET);
    HAL_GPIO_WritePin(I2C3_PORT, I2C3_SDA_PIN, GPIO_PIN_SET);

    HAL_GPIO_DeInit(I2C3_PORT, I2C3_SCL_PIN | I2C3_SDA_PIN); // Return pins to default state
}

static void LSM6DSR_Init(void) {
	uint8_t rst = 1;
	uint8_t who = 0;

	// Platform initialization
	s_lsm_ctx.write_reg = platform_write;
	s_lsm_ctx.read_reg  = platform_read;
	s_lsm_ctx.mdelay    = HAL_Delay;
	s_lsm_ctx.handle    = &g_imu_bus;

	HAL_Delay(100); // Initial power-on delay

	// Perform software reset with proper timing
	do {
		if (lsm6dsr_reset_set(&s_lsm_ctx, 1) != 0) {
			Error_Handler();
		}
		HAL_Delay(50); // Extended delay for reset completion
	} while (lsm6dsr_reset_get(&s_lsm_ctx, &rst) != 0 || rst != 0);

	// Verify device ID with retries
	for (int attempt = 0; attempt < 10; attempt++) {
		if (lsm6dsr_device_id_get(&s_lsm_ctx, &who) == 0 && who == LSM6DSR_ID) {
			break;
		}
		HAL_Delay(20);
	}

	if (who != LSM6DSR_ID) {
		Error_Handler();
	}

	// Disable I3C interface
	if (lsm6dsr_i3c_disable_set(&s_lsm_ctx, LSM6DSR_I3C_DISABLE) != 0) {
		Error_Handler();
	}

	/* Disable I3C (Mode 1: IMU is I2C slave) */
	lsm6dsr_i3c_disable_set(&s_lsm_ctx, LSM6DSR_I3C_DISABLE);

	/* Put gyroscope into power-down */
	lsm6dsr_gy_data_rate_set(&s_lsm_ctx, LSM6DSR_GY_ODR_OFF);
	/* Gryo power mode should be irrelevant (set to normal for safe default) */
	lsm6dsr_gy_power_mode_set(&s_lsm_ctx, LSM6DSR_GY_NORMAL);
	/* BDU: Blocks of registers can't be updated mid-read */
	lsm6dsr_block_data_update_set(&s_lsm_ctx, 1);

	LSM6DSR_Init_Pedo_INT2();
	/* TAP detection overrides ODR to 416Hz, setting accel to high power mode */
	// LSM6DSR_Init_Tap_INT2();

	/* Configure pin mode/polarity */
	lsm6dsr_pin_mode_set(&s_lsm_ctx, LSM6DSR_PUSH_PULL);
	lsm6dsr_pin_polarity_set(&s_lsm_ctx, LSM6DSR_ACTIVE_HIGH);
	lsm6dsr_int_notification_set(&s_lsm_ctx, LSM6DSR_ALL_INT_PULSED);

}

// Pedometer Config based on Application Note 5358
static void LSM6DSR_Init_Pedo_INT2(void) {
	/* Pedometer works at accelerometer 2g Full Scale (STMicroelectronics/lsm6dsr-pid) */
	lsm6dsr_xl_full_scale_set(&s_lsm_ctx, LSM6DSR_4g);
	/* 6.1 Pedometer functions: ODR >= 26Hz for step counter*/
	lsm6dsr_xl_data_rate_set(&s_lsm_ctx, LSM6DSR_XL_ODR_26Hz);
	/* Low power mode works @ ODR <= 26Hz*/
	lsm6dsr_xl_power_mode_set(&s_lsm_ctx, LSM6DSR_LOW_NORMAL_POWER_MD);

	/* Enable pedometer with false-step rejection */
	lsm6dsr_pedo_sens_set(&s_lsm_ctx, PROPERTY_ENABLE);
	lsm6dsr_pedo_mode_set(&s_lsm_ctx, LSM6DSR_PEDO_ADV_FALSE_STEP_REJ);
	lsm6dsr_pedo_int_mode_set(&s_lsm_ctx, LSM6DSR_EVERY_STEP);
	lsm6dsr_steps_reset(&s_lsm_ctx);
	uint8_t debounce = STEP_DEBOUNCE_THRESHOLD;
	lsm6dsr_pedo_debounce_steps_set(&s_lsm_ctx, &debounce);

	/* Route Step Detector interrupt to INT1 */
	lsm6dsr_pin_int2_route_t int2_route;
	lsm6dsr_pin_int2_route_get(&s_lsm_ctx, &int2_route);
	int2_route.emb_func_int2.int2_step_detector = 1;
	lsm6dsr_pin_int2_route_set(&s_lsm_ctx, &int2_route);
}

// Tap Detection Config based on Application Note 5358
static void LSM6DSR_Init_Tap_INT2(void) {
	/* Accelerometer works at accelerometer 2g Full Scale*/
	lsm6dsr_xl_full_scale_set(&s_lsm_ctx, LSM6DSR_2g);
	/* 5.5 Single-tap and double-tap recognition: ODR >= 416Hz for tap detection*/
	lsm6dsr_xl_data_rate_set(&s_lsm_ctx, LSM6DSR_XL_ODR_416Hz);

	/* Enable tap detection on all axes */
	lsm6dsr_tap_detection_on_x_set(&s_lsm_ctx, 1);
	lsm6dsr_tap_detection_on_y_set(&s_lsm_ctx, 1);
	lsm6dsr_tap_detection_on_z_set(&s_lsm_ctx, 1);

	/* Use slope on internal path (recommended for taps) */
	lsm6dsr_xl_hp_path_internal_set(&s_lsm_ctx, LSM6DSR_USE_SLOPE);

	/* Thresholds: 0x0C -> ~0.75 g at FS=±2 g */
	lsm6dsr_tap_threshold_x_set(&s_lsm_ctx, 0x0C);
	lsm6dsr_tap_threshold_y_set(&s_lsm_ctx, 0x0C);
	lsm6dsr_tap_threshold_z_set(&s_lsm_ctx, 0x0C);

	/* Axis priority X->Y->Z */
	lsm6dsr_tap_axis_priority_set(&s_lsm_ctx, LSM6DSR_XYZ);

	/* Time windows at ODR_XL=416 Hz (approx):
	SHOCK=3 (~57.7 ms), QUIET=3 (~28.8 ms), DUR=7 (~538.5 ms) */
	lsm6dsr_tap_shock_set(&s_lsm_ctx, 0x03);
	lsm6dsr_tap_quiet_set(&s_lsm_ctx, 0x03);
	lsm6dsr_tap_dur_set(&s_lsm_ctx, 0x07);

	/* Enable both single & double tap recognition */
	lsm6dsr_tap_mode_set(&s_lsm_ctx, LSM6DSR_BOTH_SINGLE_DOUBLE);

	/* Route interrupts to INT2 */
	lsm6dsr_pin_int2_route_t int2_route;
	lsm6dsr_pin_int2_route_get(&s_lsm_ctx, &int2_route);
	int2_route.md2_cfg.int2_single_tap = 1;
	int2_route.md2_cfg.int2_double_tap = 1;
	lsm6dsr_pin_int2_route_set(&s_lsm_ctx, &int2_route);
}

static void MAX31331_Init(void) {
	uint8_t seconds = 0;
	uint8_t minutes = 0;
	uint8_t hours   = 14;  // Example: 2PM
	uint8_t day     = 3;   // WEDNESDAY
	uint8_t date    = 27;  // 27th
	uint8_t month   = 8;   // January
	uint8_t year    = 25;  // Year = 2025 (last two digits)
	uint8_t century = 0;   // 0 = 21st century, 1 = 22nd century

	s_max_ctx.write_reg = platform_write;
	s_max_ctx.read_reg  = platform_read;
	s_max_ctx.mdelay    = HAL_Delay;
	s_max_ctx.handle    = &g_rtc_bus;

	HAL_Delay(20);

	max31331_reset_rtc(&s_max_ctx);
	HAL_Delay(5);

	max31331_set_time(&s_max_ctx, seconds, minutes, hours);
	seconds 	= 0xFF;
	minutes 	= 0xFF;
	hours   	= 0xFF;
	uint8_t format 	= 0xFF;
	HAL_Delay(5);
	
	max31331_get_time(&s_max_ctx, &seconds, &minutes, &hours, &format);
	HAL_Delay(5);

	max31331_set_date(&s_max_ctx, day, date, month, century, year);
	day     = 0xFF;
	date    = 0xFF;
	month   = 0xFF;
	year    = 0xFF;
	century = 0xFF;
	HAL_Delay(5);
	
	max31331_get_date(&s_max_ctx, &day, &date, &month, &century, &year);
	HAL_Delay(5);

	// Enable 1hz clko for display
	// max31331_set_clko(&s_max_ctx, 1, CLKO_1Hz);
	// HAL_Delay(5);

	max31331_set_timer_config(&s_max_ctx, 0, 0, 1, TIMER_16Hz); // Disable timer and "resume" to change init
	HAL_Delay(5);
	max31331_set_timer_init(&s_max_ctx, 16);                   	// Update init to get interrupts every 16 ticks
	HAL_Delay(5);
	max31331_set_timer_config(&s_max_ctx, 1, 0, 1, TIMER_16Hz); // 16hz timer every 16 ticks => 1hz interrupt
	HAL_Delay(5);
	
	max31331_set_int_en(&s_max_ctx, 0, 0, 0, 0, 1, 0, 0);      // Enable timer interrupt only
	uint8_t int_en = 0xFF;
	HAL_Delay(5);
	max31331_get_int_en(&s_max_ctx, &int_en);
	HAL_Delay(5);
	uint8_t rtc_status = 0xFF;
	max31331_get_status(&s_max_ctx, &rtc_status);
	HAL_Delay(5);
}

/* ============== LP-Run modes ============== */
void Enter_LowPowerRunMode(void)
{
    RCC_OscInitTypeDef RCC_OscInitStruct = {0};
    RCC_ClkInitTypeDef RCC_ClkInitStruct = {0};

    // Step 1: Switch to MSI
    RCC_OscInitStruct.OscillatorType = RCC_OSCILLATORTYPE_MSI;
    RCC_OscInitStruct.MSIState = RCC_MSI_ON;
    RCC_OscInitStruct.MSICalibrationValue = 0;
    RCC_OscInitStruct.MSIClockRange = RCC_MSIRANGE_4;
    RCC_OscInitStruct.PLL.PLLState = RCC_PLL_NONE;
    if (HAL_RCC_OscConfig(&RCC_OscInitStruct) != HAL_OK) {
        Error_Handler();
    }

    RCC_ClkInitStruct.ClockType      = RCC_CLOCKTYPE_HCLK |
                                       RCC_CLOCKTYPE_SYSCLK |
                                       RCC_CLOCKTYPE_PCLK1;
    RCC_ClkInitStruct.SYSCLKSource   = RCC_SYSCLKSOURCE_MSI;
    RCC_ClkInitStruct.AHBCLKDivider  = RCC_SYSCLK_DIV1;
    RCC_ClkInitStruct.APB1CLKDivider = RCC_HCLK_DIV1;

    if (HAL_RCC_ClockConfig(&RCC_ClkInitStruct, FLASH_LATENCY_0) != HAL_OK) {
        Error_Handler();
    }

    // Step 2: Enable Low Power Run Mode
    HAL_PWREx_EnableLowPowerRunMode();
    inLPRunMode = 1;
}

void Exit_LowPowerRunMode(void)
{
    RCC_OscInitTypeDef RCC_OscInitStruct = {0};
    RCC_ClkInitTypeDef RCC_ClkInitStruct = {0};
    uint32_t flashLatency = FLASH_LATENCY_0;

    // Step 1: Disable Low Power Run Mode
    HAL_PWREx_DisableLowPowerRunMode();
    inLPRunMode = 0;

    // Step 2: Switch back to HSI 16 MHz
    RCC_OscInitStruct.OscillatorType = RCC_OSCILLATORTYPE_HSI;
    RCC_OscInitStruct.HSIState = RCC_HSI_ON;
    RCC_OscInitStruct.HSICalibrationValue = RCC_HSICALIBRATION_DEFAULT;
    if (HAL_RCC_OscConfig(&RCC_OscInitStruct) != HAL_OK) {
        Error_Handler();
    }

    // Decide FLASH latency based on current VOS
    switch (HAL_PWREx_GetVoltageRange()) {
        case PWR_REGULATOR_VOLTAGE_SCALE1:  
            flashLatency = FLASH_LATENCY_0;  // up to 16 MHz
            break;
        case PWR_REGULATOR_VOLTAGE_SCALE2:  
            flashLatency = FLASH_LATENCY_1;  // 16 MHz needs 1 WS
            break;
        default: 
            Error_Handler();  // not valid for 16 MHz
            break;
    }

    // Switch SYSCLK back to HSI
    RCC_ClkInitStruct.ClockType      = RCC_CLOCKTYPE_HCLK |
                                       RCC_CLOCKTYPE_SYSCLK |
                                       RCC_CLOCKTYPE_PCLK1;
    RCC_ClkInitStruct.SYSCLKSource   = RCC_SYSCLKSOURCE_HSI;
    RCC_ClkInitStruct.AHBCLKDivider  = RCC_SYSCLK_DIV1;
    RCC_ClkInitStruct.APB1CLKDivider = RCC_HCLK_DIV1;

    if (HAL_RCC_ClockConfig(&RCC_ClkInitStruct, flashLatency) != HAL_OK) {
        Error_Handler();
    }
}

/* ============== EXTI IRQ Handler ============== */
void HAL_GPIO_EXTI_Falling_Callback(uint16_t GPIO_Pin) {
	if (GPIO_Pin == RTC_INT_Pin) {
		if (timeInQueue < 2) {
			if (enqueueJob(&jobQueue, timeJob)) {
				timeInQueue++;
			}
		}
	}
}

void HAL_GPIO_EXTI_Rising_Callback(uint16_t GPIO_Pin) {
	if (GPIO_Pin == IMU_INT2_Pin) {
		if (stepsInQueue < 2) {
			if (enqueueJob(&jobQueue, stepJob)) {
				stepsInQueue++;
			}
		}
	}
	if (GPIO_Pin == IMU_INT1_Pin) { // INT 1 is disabled for now
		if (tapsInQueue < 2) {
			if (enqueueJob(&jobQueue, tapJob)) {
				tapsInQueue++;
			}
		}
	}
}

void HAL_I2C_MemRxCpltCallback(I2C_HandleTypeDef *hi2c)
{
	if(hi2c == &hi2c3) {
		if (TickDMAflag) {
			TickDMAflag = 0;
			TickRXcomp = 1;
		} else if (TapDMAflag) {
			TapDMAflag = 0;
			TapRXcomp = 1;
		} else if (StepDMAflag) {
			StepDMAflag = 0;
			StepRXcomp = 1;
		}
  }
	DMArunning = 0;
}

/* ============== Platform Specific Read/Write ============== */
static int32_t platform_write(void *handle, uint8_t reg, const uint8_t *bufp, uint16_t len)
{
	i2c_dev_t *dev = (i2c_dev_t *)handle;
	if (HAL_I2C_Mem_Write(dev->i2c, (dev->addr_8bit), reg,
							I2C_MEMADD_SIZE_8BIT, (uint8_t*)bufp, len, 100) != HAL_OK)
		return -1;
	return 0;
}

static int32_t platform_read(void *handle, uint8_t reg, uint8_t *bufp, uint16_t len)
{
	i2c_dev_t *dev = (i2c_dev_t *)handle;
	if (HAL_I2C_Mem_Read(dev->i2c, (dev->addr_8bit), reg,
							I2C_MEMADD_SIZE_8BIT, bufp, len, 100) != HAL_OK)
	return -1;
	return 0;
}

/* USER CODE END 4 */
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


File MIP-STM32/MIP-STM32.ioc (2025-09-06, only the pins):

Mcu.UserName=STM32U031C8Tx
PA0.GPIO_Label=IMU_INT2
PA0.Signal=GPXTI0
PA1.GPIO_Label=IMU_INT1_Float
PA1.Signal=GPIO_Input
PA10.GPIO_Label=SI2
PA10.Signal=GPIO_Output
PA15.GPIO_Label=DEN
PA15.Signal=GPIO_Output
PA2.GPIO_Label=RTC_INT
PA2.Signal=GPXTI2
PA3.Signal=GPIO_Analog
PA4.Signal=GPIO_Analog
PA5.Signal=GPIO_Analog
PA6.Signal=I2C3_SDA
PA7.Signal=I2C3_SCL
PA8.GPIO_Label=DISP_SCLK
PA8.Signal=GPIO_Analog
PA9.GPIO_Label=SI3
PA9.Signal=GPIO_Output
PB0.Signal=GPIO_Analog
PB1.GPIO_Label=Vcom_Sel
PB1.Signal=GPIO_Output
PB10.GPIO_Label=XRST
PB10.Signal=GPIO_Output
PB11.GPIO_Label=ENBS
PB11.Signal=GPIO_Output
PB12.GPIO_Label=SI7
PB12.Signal=GPIO_Output
PB13.GPIO_Label=SI6
PB13.Signal=GPIO_Output
PB14.GPIO_Label=SI5
PB14.Signal=GPIO_Output
PB15.GPIO_Label=SI4
PB15.Signal=GPIO_Output
PB2.Signal=GPIO_Analog
PB3.Signal=GPIO_Analog
PB4.GPIO_Label=ENBG
PB4.Signal=GPIO_Output
PB5.Signal=GPIO_Analog
PB6.Signal=GPIO_Analog
PB7.Signal=GPIO_Analog
PB8.Signal=GPIO_Analog
PB9.Signal=GPIO_Analog
PC13.Signal=GPIO_Analog
PC14-OSC32_IN.Signal=GPIO_Analog
PC15-OSC32_OUT.Signal=GPIO_Analog
PF0-OSC_IN.Signal=RCC_OSC_IN
PF1-OSC_OUT.Signal=RCC_OSC_OUT

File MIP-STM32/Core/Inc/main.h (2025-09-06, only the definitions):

#define IMU_INT2_Pin GPIO_PIN_0
#define IMU_INT2_GPIO_Port GPIOA
#define IMU_INT2_EXTI_IRQn EXTI0_1_IRQn
#define IMU_INT1_Float_Pin GPIO_PIN_1
#define IMU_INT1_Float_GPIO_Port GPIOA
#define RTC_INT_Pin GPIO_PIN_2
#define RTC_INT_GPIO_Port GPIOA
#define RTC_INT_EXTI_IRQn EXTI2_3_IRQn
#define Vcom_Sel_Pin GPIO_PIN_1
#define Vcom_Sel_GPIO_Port GPIOB
#define XRST_Pin GPIO_PIN_10
#define XRST_GPIO_Port GPIOB
#define ENBS_Pin GPIO_PIN_11
#define ENBS_GPIO_Port GPIOB
#define SI7_Pin GPIO_PIN_12
#define SI7_GPIO_Port GPIOB
#define SI6_Pin GPIO_PIN_13
#define SI6_GPIO_Port GPIOB
#define SI5_Pin GPIO_PIN_14
#define SI5_GPIO_Port GPIOB
#define SI4_Pin GPIO_PIN_15
#define SI4_GPIO_Port GPIOB
#define DISP_SCLK_Pin GPIO_PIN_8
#define DISP_SCLK_GPIO_Port GPIOA
#define SI3_Pin GPIO_PIN_9
#define SI3_GPIO_Port GPIOA
#define SI2_Pin GPIO_PIN_10
#define SI2_GPIO_Port GPIOA
#define SI1_Pin GPIO_PIN_11
#define SI1_GPIO_Port GPIOA
#define SI0_Pin GPIO_PIN_12
#define SI0_GPIO_Port GPIOA
#define DBG_SWDIO_Pin GPIO_PIN_13
#define DBG_SWDIO_GPIO_Port GPIOA
#define DBG_SWCLK_Pin GPIO_PIN_14
#define DBG_SWCLK_GPIO_Port GPIOA
#define DEN_Pin GPIO_PIN_15
#define DEN_GPIO_Port GPIOA
#define ENBG_Pin GPIO_PIN_4
#define ENBG_GPIO_Port GPIOB

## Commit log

2025-08-06 Added KiCad files
    [MIP_Schematics.kicad_pcb, MIP_Schematics.kicad_sch, bom.csv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]
2025-08-28 V2 of the MIP Watch - Updated PCB - Added test points - Uses single LDO for power regulation - Changed IMU to LSM6DSR - Added STM32 Code. - Functional prototype with interrupt based peripheral reads.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
    [MIP-PCB.kicad_pcb, MIP-PCB.kicad_sch, MIP_Schematics.kicad_pcb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]
2025-08-29 MIP Watch V2: Added STM32 project files. - Updated README.md - Disabled IMU_INT1 to avoid I3C conflict.
    [MIP-STM32.ioc, lsm6dsr_reg.h, main.c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]
2025-08-29 Enabled STOP/SLEEP modes! Fixed typos in README
    [main.c]
2025-09-06 Added Low-Power Run Mode (1MHz Clock) Disabled MCO2 to save power Configured unsused pins as analog

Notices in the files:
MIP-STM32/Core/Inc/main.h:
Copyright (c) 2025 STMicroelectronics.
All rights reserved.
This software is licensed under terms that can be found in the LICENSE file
